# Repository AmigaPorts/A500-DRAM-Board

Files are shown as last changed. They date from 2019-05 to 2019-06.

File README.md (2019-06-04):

# A500-DRAM-Board
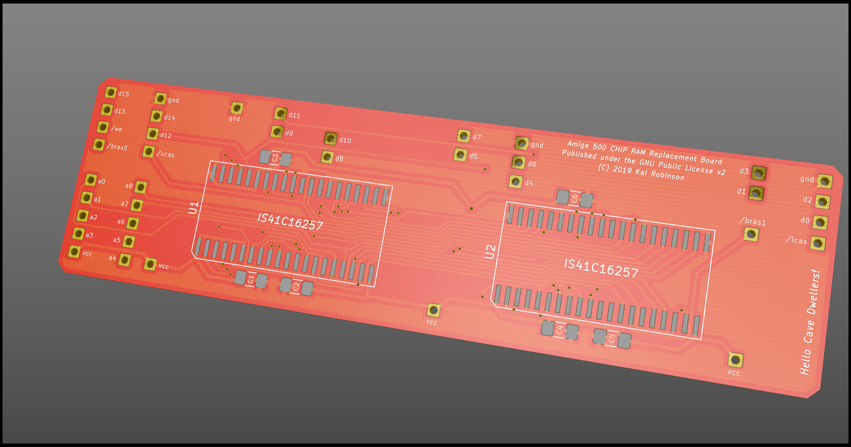
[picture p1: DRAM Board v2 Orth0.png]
A500 DRAM Replacement Board


Replace the old 44256 DRAM chips on your A500+ with newer EDO memory! No more hunting around trying to find stocks of old 44256 DRAM chips on eBay from dubious sellers with no idea if they work or not - i designed this board to fit 2 x 512KB (4MBit) EDO RAM chips so that you can address 1MB of RAM.

I used IS41C16257-35 chips (256k x 16) as they're cheap, abundant and they have exactly 9 address lines (A0 to A8) so no need for a CPLD to generate the A9 signal that's required for newer chips.

It's a pretty simple design, just three decoupling caps for each DRAM IC and the correct pin layout for it to plug into the A500 board. 

This Rev2 design reduces the component count, the board size and improves the layout and routing considerably.

Project is all done in KiCad 5.1.2

# Bill of Materials

6 x X7R 0.1uF MLCC SMD Capacitors (1206 (imperial))

2 x IS41C16257-35 5v 256x16 EDO DRAM (SOJ-40)

4 x 10-pin SIL Headers (Harwin M20-9771042)

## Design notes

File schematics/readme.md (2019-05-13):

Remember to grab the A500 Parts Library so that you have the correct footprints.

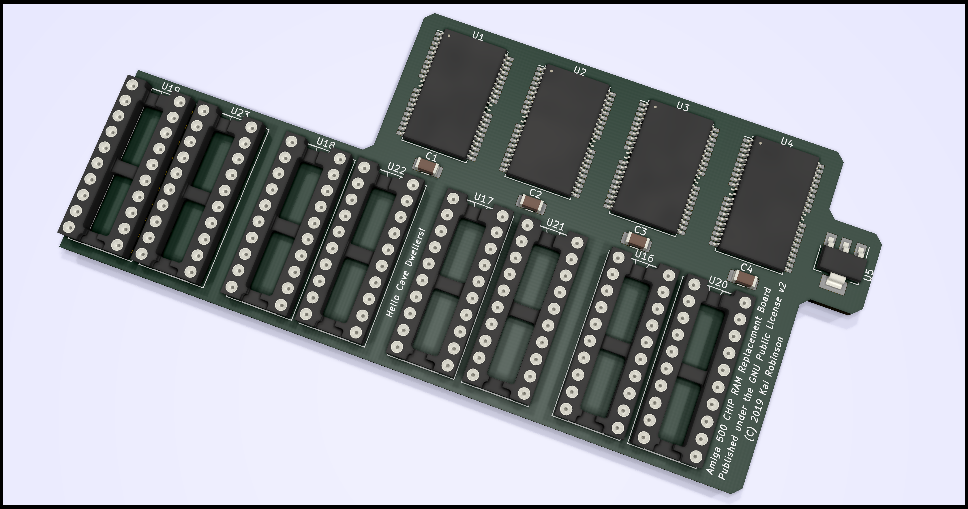
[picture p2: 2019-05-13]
DRAM Board Rev0 Orthog3.png

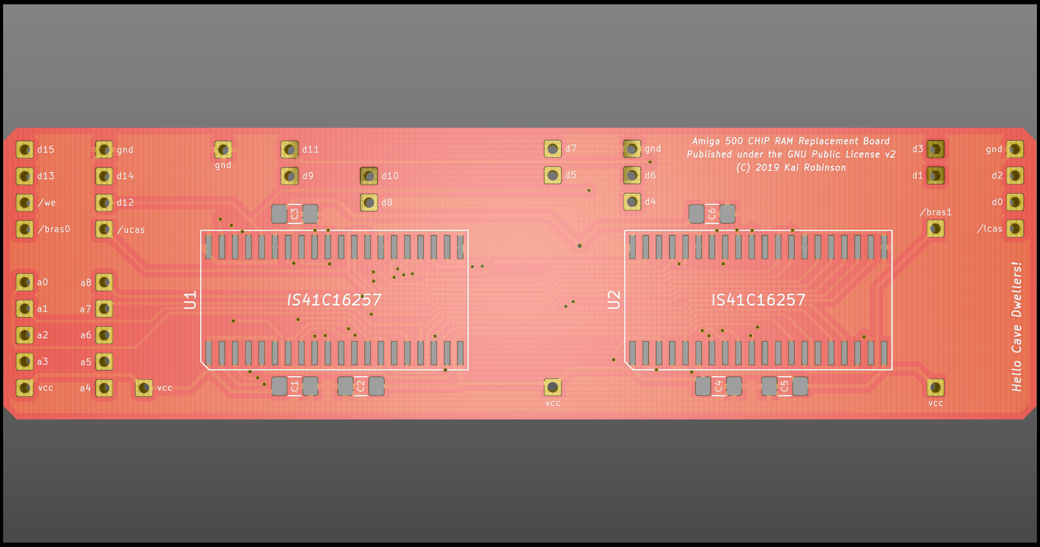
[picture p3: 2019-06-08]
DRAM Board v2 Top0.png

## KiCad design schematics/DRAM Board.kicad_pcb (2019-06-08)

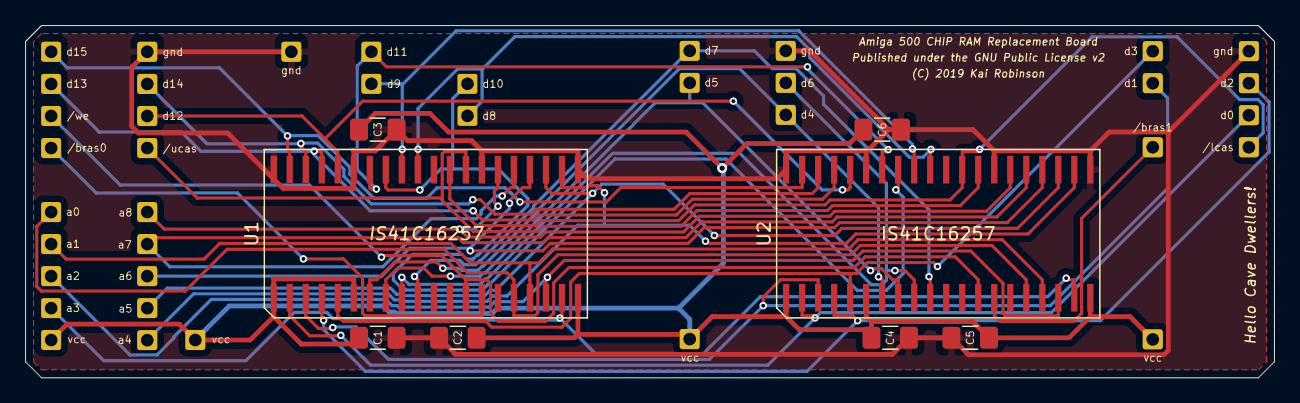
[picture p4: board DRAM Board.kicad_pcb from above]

Board: 2 copper layers, 99.1 x 27.9 mm, 46 parts (0 on the bottom side), 32 nets.

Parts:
/bras0, /bras1: Conn_01x01; PinHeader_1x01_P2.54mm_Vertical
/lcas: Conn_01x01; PinHeader_1x01_P2.54mm_Vertical
/ucas: Conn_01x01; PinHeader_1x01_P2.54mm_Vertical
/we: Conn_01x01; PinHeader_1x01_P2.54mm_Vertical
C1, C2, C3, C4, C5, C6: 0.1uF; C_1206_3216Metric_Pad1.42x1.75mm_HandSolder
U1, U2: IS41C16257; SOJ-40
a0, a1, a2, a3, a4, a5, a6, a7, a8: Conn_01x01; PinHeader_1x01_P2.54mm_Vertical
d0, d1, d2, d3, d4, d5, d6, d7, d8, d9, d10, d11, d12, d13, d14, d15: Conn_01x01; PinHeader_1x01_P2.54mm_Vertical
gnd: Conn_01x01; PinHeader_1x01_P2.54mm_Vertical
gnd_u19, gnd_u20, gnd_u23: Conn_01x01; PinHeader_1x01_P2.54mm_Vertical
vcc_u17, vcc_u19, vcc_u20, vcc_u23: Conn_01x01; PinHeader_1x01_P2.54mm_Vertical

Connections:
/_bras0: /bras0.1, U1.14
/_bras1: /bras1.1, U2.14
/_lcas: /lcas.1, U1.29, U2.29
/_ucas: /ucas.1, U1.28, U2.28
/_we: /we.1, U1.13, U2.13
/a0: U1.16, U2.16, a0.1
/a1: U1.17, U2.17, a1.1
/a2: U1.18, U2.18, a2.1
/a3: U1.19, U2.19, a3.1
/a4: U1.22, U2.22, a4.1
/a5: U1.23, U2.23, a5.1
/a6: U1.24, U2.24, a6.1
/a7: U1.25, U2.25, a7.1
/a8: U1.26, U2.26, a8.1
/d0: U1.2, U2.2, d0.1
/d1: U1.3, U2.3, d1.1
/d2: U1.4, U2.4, d2.1
/d3: U1.5, U2.5, d3.1
/d4: U1.7, U2.7, d4.1
/d5: U1.8, U2.8, d5.1
/d6: U1.9, U2.9, d6.1
/d7: U1.10, U2.10, d7.1
/d8: U1.31, U2.31, d8.1
/d9: U1.32, U2.32, d9.1
/d10: U1.33, U2.33, d10.1
/d11: U1.34, U2.34, d11.1
/d12: U1.36, U2.36, d12.1
/d13: U1.37, U2.37, d13.1
/d14: U1.38, U2.38, d14.1
/d15: U1.39, U2.39, d15.1
/gnd: C1.2, C2.2, C3.2, C4.2, C5.2, C6.2, U1.21, U1.27, U1.35, U1.40, U2.21, U2.27, U2.35, U2.40, gnd.1, gnd_u19.1, gnd_u20.1, gnd_u23.1
/vcc5: C1.1, C2.1, C3.1, C4.1, C5.1, C6.1, U1.1, U1.6, U1.20, U2.1, U2.6, U2.20, vcc_u17.1, vcc_u19.1, vcc_u20.1, vcc_u23.1

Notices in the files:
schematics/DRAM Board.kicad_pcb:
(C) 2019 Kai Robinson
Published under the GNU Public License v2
